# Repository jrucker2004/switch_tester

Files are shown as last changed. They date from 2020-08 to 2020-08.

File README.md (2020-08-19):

# Keyboard Switch Testing

This repository is a place to store my findings while testing switches.  The testing rig was designed and built by myself, and I plan on releasing build instructions for it once I work out all of the bugs.  

# Dislcaimers

I'm not an expert! This is just a hobby, treat it as such.

It's important to note that The data you find in this repository is for reference only.  The testing rig I'm using is calibrated using tools I have on-hand, and will very likely not create the same results as a testing rig someone else has built.  For this reason, I do not plan on releasing the raw test data.  I am making the results of my testing freely available by way of fancy looking graphs.  I'm currently using Splunk to visualize the data, but there are some downsides, like limits to how much formatting can be done to the graph, and what is displayed.  If you know of a better tool, please let me know.

# Included in this repository

You'll find the following things in this repository:

### Switch_List.csv

This is a list of the switches I have tested, or have on-hand to test.  The majority of these switches were sent to me to test by generous volunteers.  Note that some switches have been lubricated, and some have not.  Unfortunately I'm at the whim of what is sent to me, so I can only record what I've been sent to test. I would prefer to test un-lubricated switches, because method of lubrication by different users can result in different results.  If you have a switch you'd like to see tested that isn't on the list, please send me a message.

### Directories

Several directories, broken out by switch manufacturer.  In each directory, you'll find subdirectories of switch models.  In there, you'll find graphs that I've created that show the actuation force graphed against travel distance.  The vertical lines are the actuation points of the switches.  Unless otherwise noted, each switch is compressed and released 5 times.  The graphs titled "Average" are an average of all tests, showing both compression and release.  The graphs titled "Compressing" and "Releasing" show the data from all test runs.

You'll also find a directory called "Comparisons".  In this directory are graphs that compare different switches.  If there is a comparison that isn't present that you'd like to see, create an issue with the label "Comparison Request".

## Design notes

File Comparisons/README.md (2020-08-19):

### Comparisons

This directory contains visual comparisons of various switches.  To keep graphs from getting too cluttered or difficult to read, I have split them up into "Compressing" and "Releasing".

If there is a comparison you'd like to see, submit a new issue with the label "Comparison Request"

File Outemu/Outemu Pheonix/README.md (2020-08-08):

This switch ended up being very inconsistent.  I initially thought there was something wrong wtih my test rig, but the results were similar over 10 tests runs.  The way this switch implements the click function results in the place the click happens to be different depending on how the internal parts are aligned while being depressed.  The release stroke is far more consistent, however.  While investigating, if I applied pressure towards the back of the switch while depressing, the cilck happened much sooner in the stroke than if I was applying pressure towards the front of the switch.  As a result, the "Average" graph doesn't show a true representation of what this switch feels like.

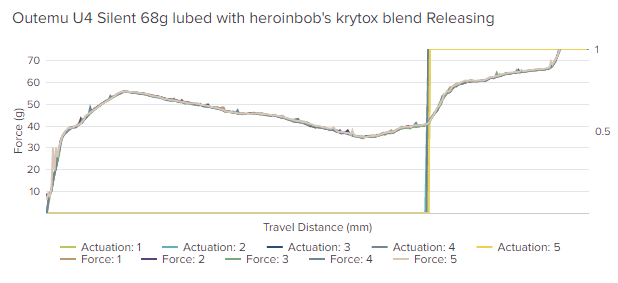
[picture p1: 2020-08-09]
Outemu/Outemu U4 Silent 68g/Outemu U4 Silent 68g Releasing.png

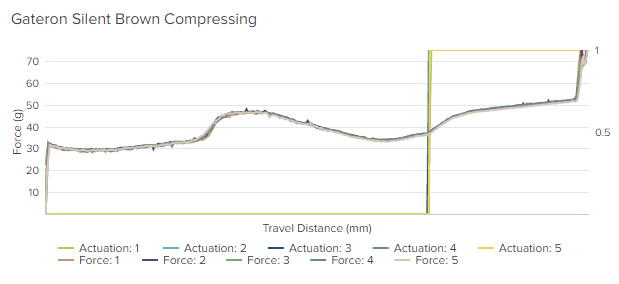
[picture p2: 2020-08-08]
Gateron/Gateron Silent Brown/Gateron Silent Brown Compressing.png

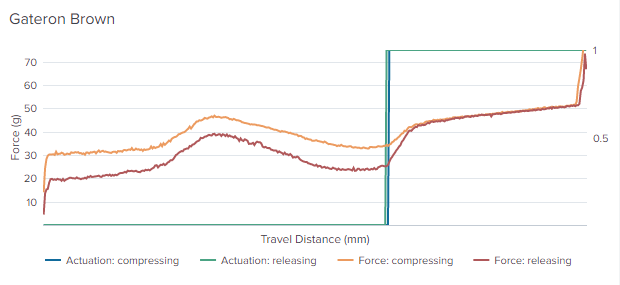
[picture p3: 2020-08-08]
Gateron/Gateron Brown/Gateron Brown Average.png

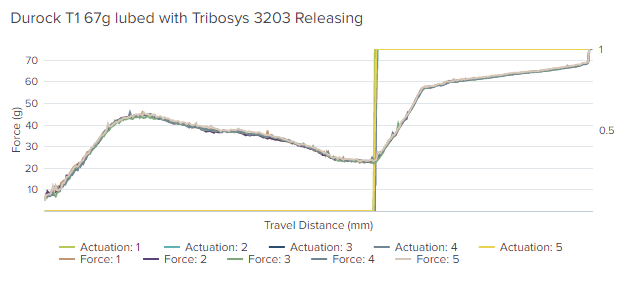
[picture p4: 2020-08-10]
Durock/Durock T1/Durock T1 67g Releasing.png

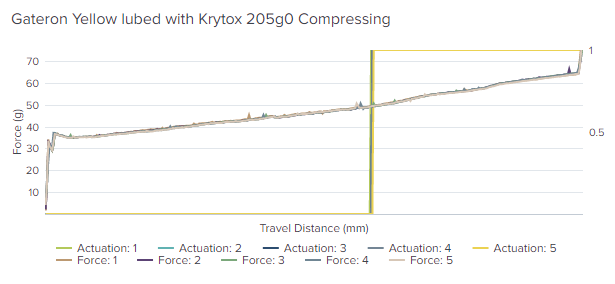
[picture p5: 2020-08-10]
Gateron/Gateron Yellow/Gateron Yellow Compressing.png

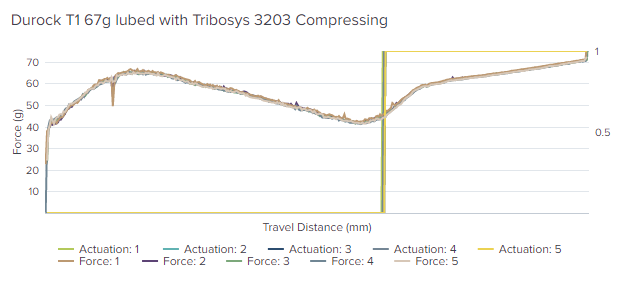
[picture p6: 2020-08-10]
Durock/Durock T1/Durock T1 67g Compressing.png

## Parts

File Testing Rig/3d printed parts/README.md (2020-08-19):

### 3D printed parts

Note:  I work in imperial (I know, I'm the worst) so these files will show up tiny when you open them in cura.  Download the barbarian plugin in Cura to fix them.

* base1
	* This file is untested.  It was modified from the version I'm currently using to try and improve how the linear rod is gripped.
* base2
	* This file is untested.  It was modified from the version I'm currently using to try and improve how the linear rod is gripped.
* coupler
	* This couples the stepper motor to the leasd screw.  The stepper motor I bought came with a coupler for a different sized lead screw, I used the set screws that came with that coupler.
* nut carrier
	* The nut for the lead screw goes into this, and is attached to the bottom of the carriage.
* nut carrier block
	* This helps hold the lead screw nut into the nut carrier.
* carriage
* fixture plate
	* I designed this to be used for more than just keyboard switches.  This fixture allows you to attach things to hold parts you want to test.
* load cell base
* pusher
* scale holder
* scale reader holder
* switch holder
	* This will hold a switch without using the fixture plate.
* switch holder 2
	* This goes with the fixture plate.

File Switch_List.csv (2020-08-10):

Switch Manufacturer | Switch Model | Tested | Lubrication
C³Equalz | Tangerine 67g | Yes | None
Durock | T1 67g | Yes | Tribosys 3203
Frankenswitch | Holy Panda | Yes | Krytox 205g0
Gateron | Brown | Yes | None
Gateron | Silent Brown | Yes | None
Gateron | Yellow | Yes | Krytox 205g0
Kailh | Box Navy | Yes | None
Novelkeys | Blueberry | Yes | heronibob’s krytox blend
Novelkeys | Cream | Yes | None
Outemu | Phoenix 68g | Yes | None
Outemu | Silent Sky 2.2 68g | Yes | Tribosys 3203
Outemu | U4 Silent 68g | Yes | heronibob’s krytox blend
Zeal | Zilent V2 65g | Yes | None

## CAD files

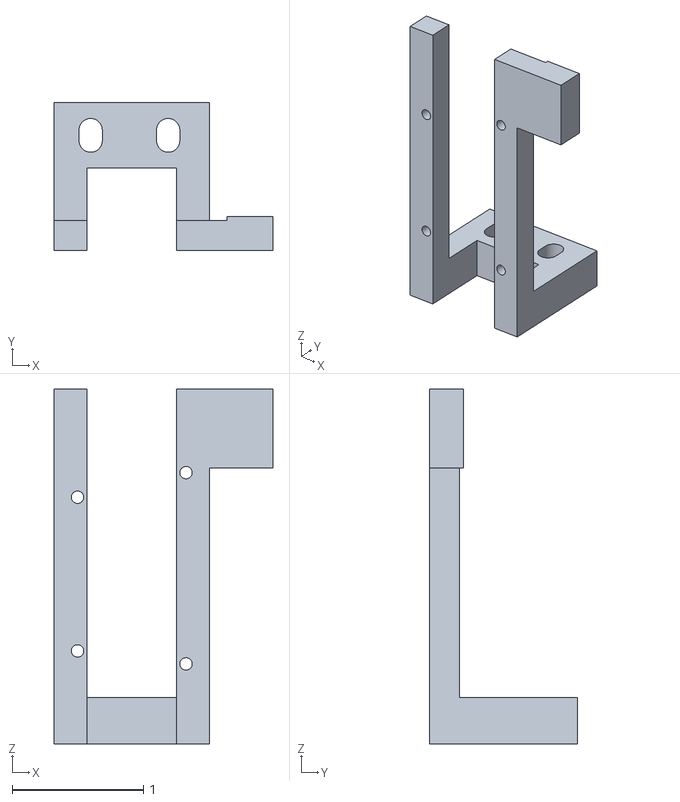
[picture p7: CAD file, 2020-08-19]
Testing Rig/3d printed parts/scale reader holder.stl
1.67 x 1.13 x 2.70

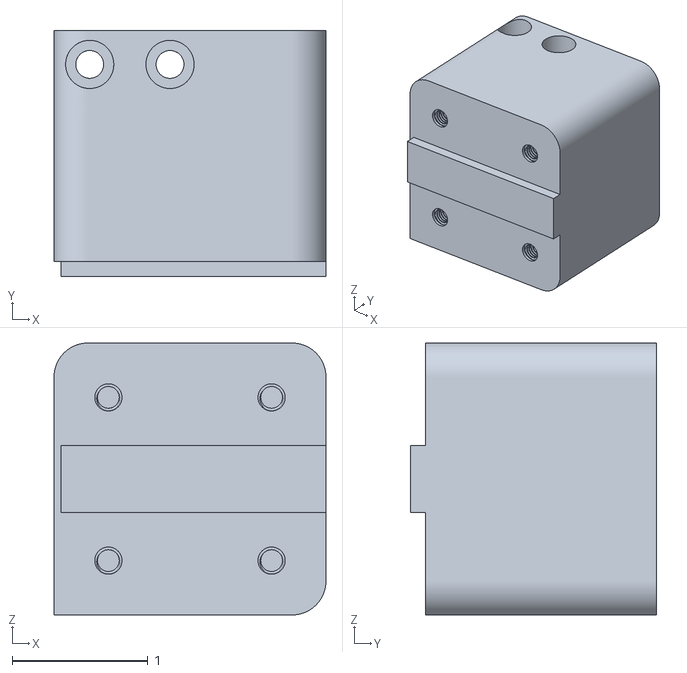
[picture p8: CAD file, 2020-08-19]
Testing Rig/3d printed parts/load cell base.stl
2.00 x 1.81 x 2.00

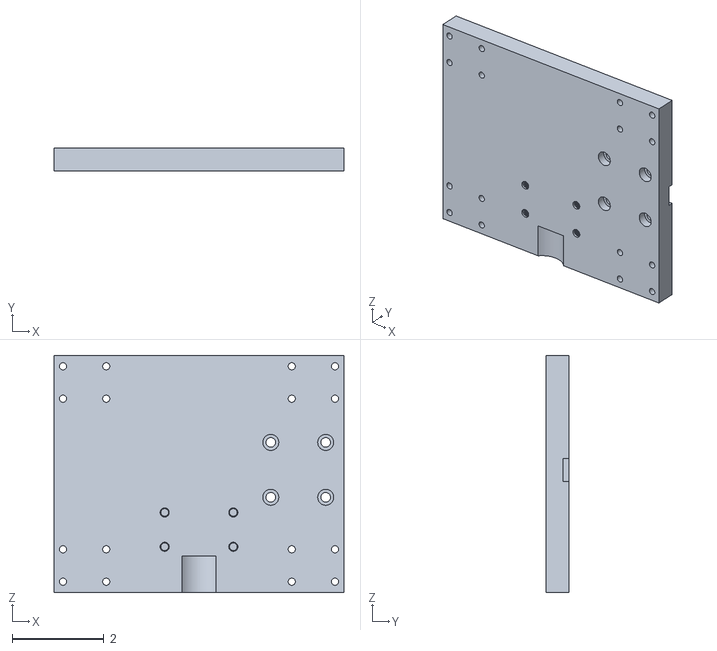
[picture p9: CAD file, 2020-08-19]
Testing Rig/3d printed parts/carriage.stl
6.34 x 0.5 x 5.18

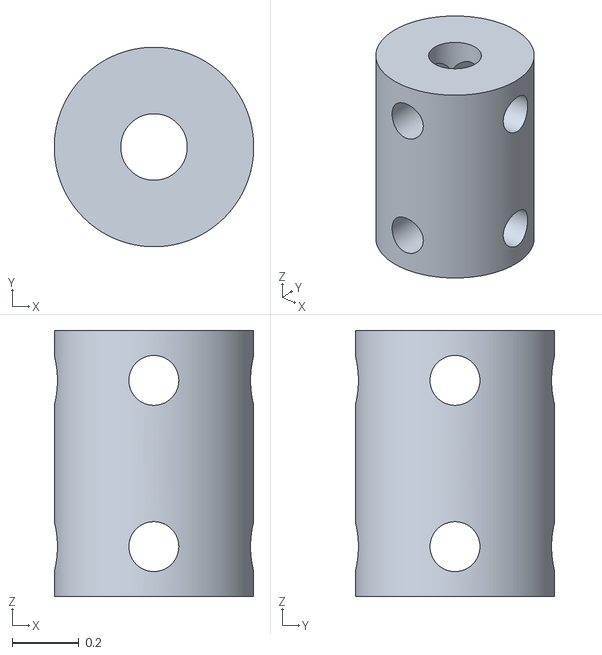
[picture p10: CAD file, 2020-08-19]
Testing Rig/3d printed parts/coupler.stl
0.6 x 0.6 x 0.8

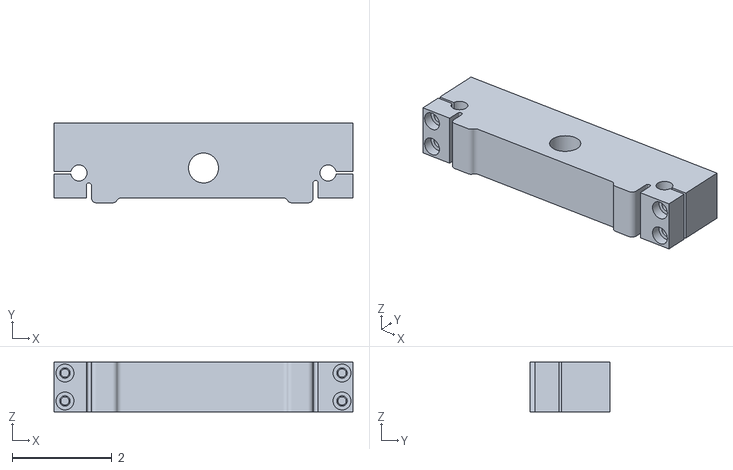
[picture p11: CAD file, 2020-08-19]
Testing Rig/3d printed parts/base2.stl
6.00 x 1.60 x 1.00

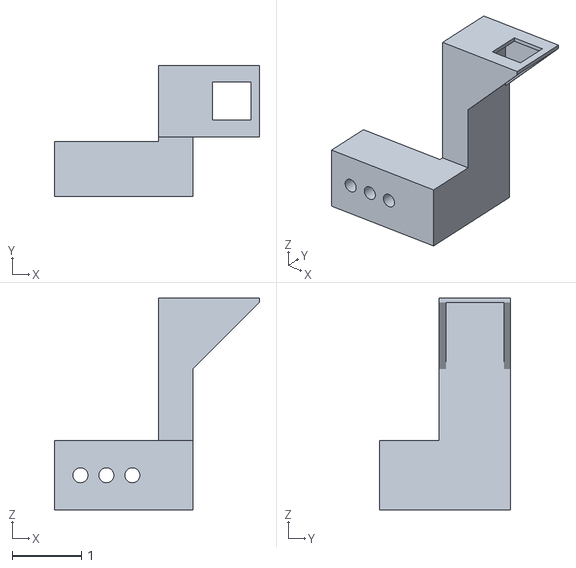
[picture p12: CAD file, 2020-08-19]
Testing Rig/3d printed parts/switch holder.stl
2.96 x 1.90 x 3.06

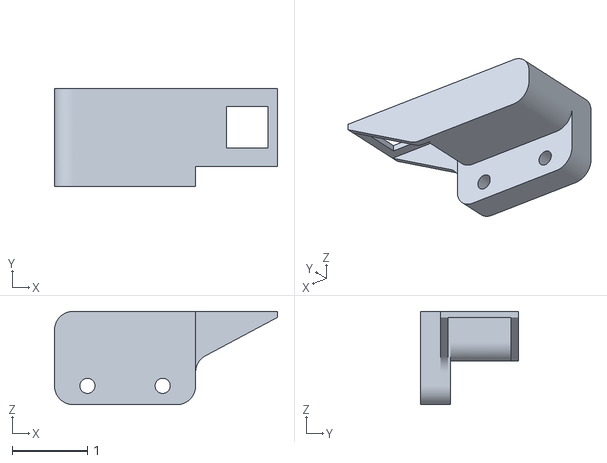
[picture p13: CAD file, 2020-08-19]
Testing Rig/3d printed parts/switch holder 2.stl
2.96 x 1.30 x 1.24

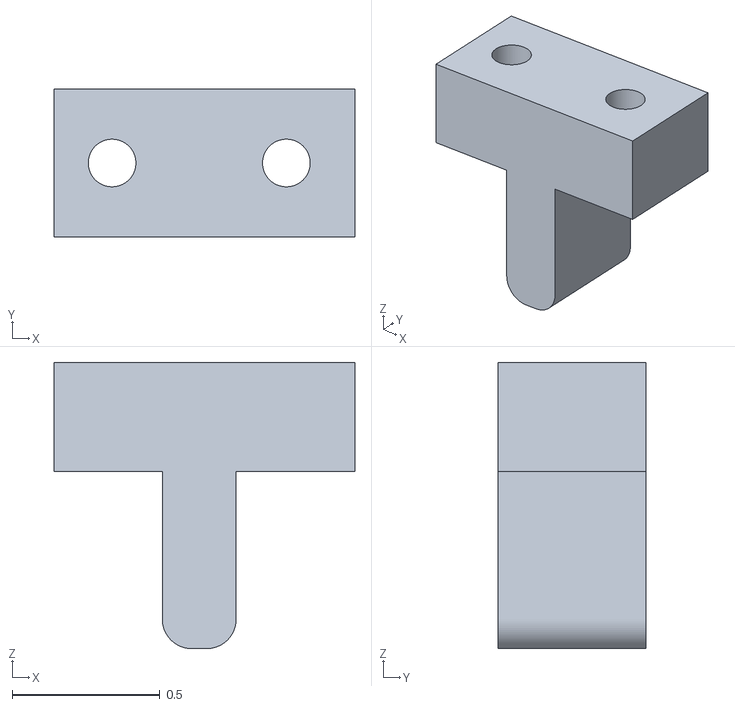
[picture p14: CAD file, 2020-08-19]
Testing Rig/3d printed parts/pusher.stl
1.02 x 0.5 x 0.97

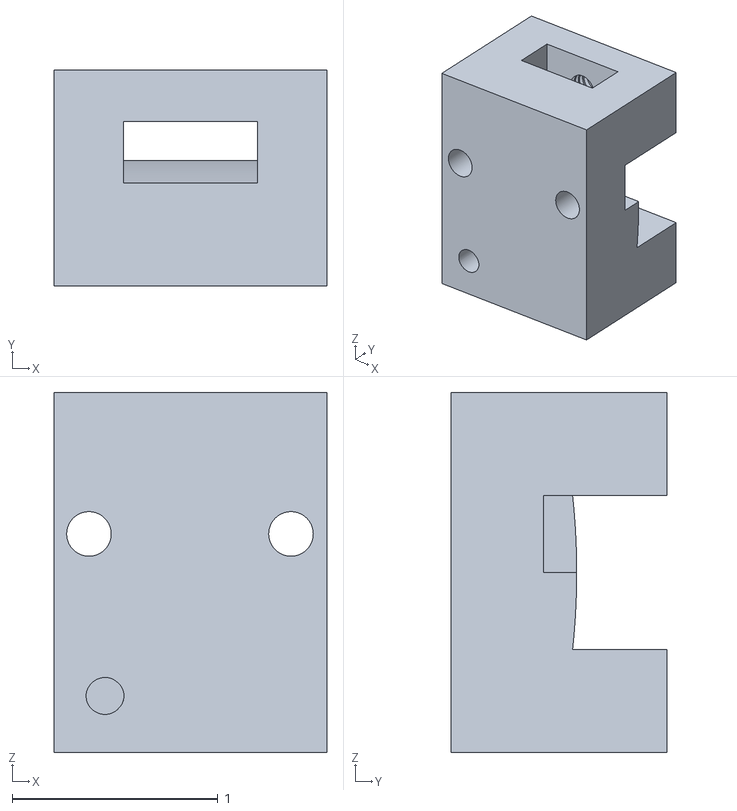
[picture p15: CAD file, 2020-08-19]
Testing Rig/3d printed parts/scale holder.stl
1.33 x 1.05 x 1.75

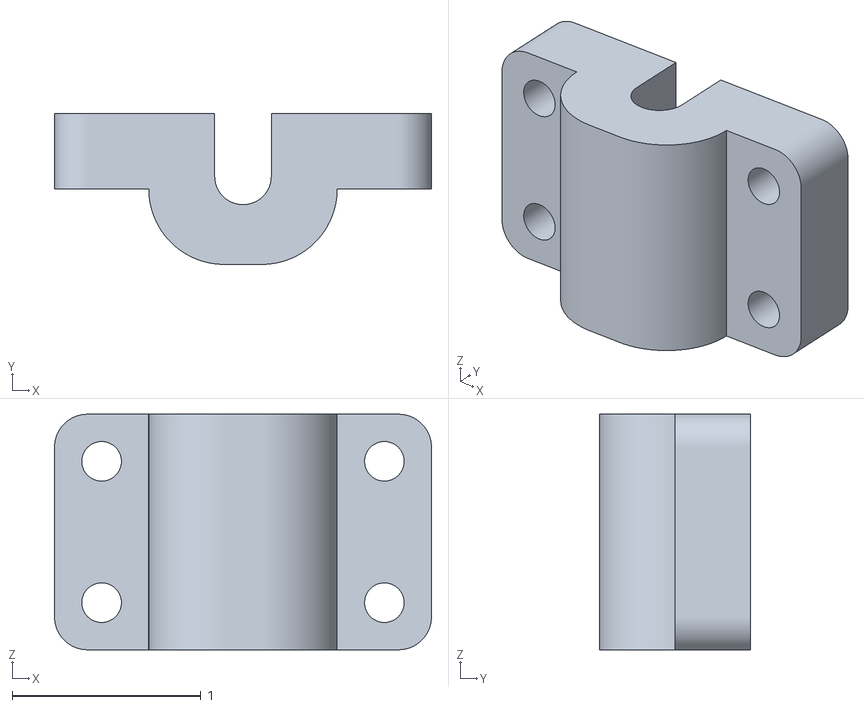
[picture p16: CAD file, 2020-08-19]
Testing Rig/3d printed parts/nut carrier.stl
2.00 x 0.8 x 1.25

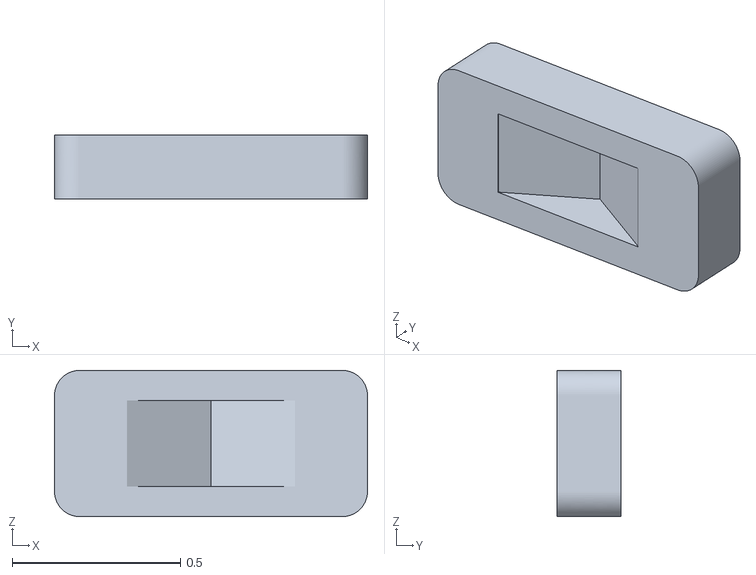
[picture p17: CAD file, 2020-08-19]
Testing Rig/3d printed parts/nut carrier block.stl
0.93 x 0.19 x 0.434

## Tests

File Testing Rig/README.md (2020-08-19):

# Testing Rig

### Overview

The purpose of this testing rig is to measure force over a distance.
Note that this was done on a budget.  All of these parts can be purchased inexpensively, but appear to be giving good results so far.  As a result of the budget, there are some limitations.  The biggest one is that the sample rate is slow enough that good force measurements cannot be taken while the stepper motor is moving.  As a result, it can take a long time to perform a test run.

### Hardware

* Load cell
	* https://www.aliexpress.com/item/32860114708.html?spm=a2g0s.9042311.0.0.5fac4c4d4d88OH
	* The load cell I used came with the load cell converter board, however I wouldn't suggest using it.
* Load Cell Converter
	* The load cell converter board is an hx711.  There are multiple versions of this board.  The one included with the load cell I purchased generations a fair amount of noise.  I've filtered out most of the noise in my code, but not all of it.  I've read that there is a version of the hx711 that uses larger capicators that remove a lot of the noise, but I haven't tested with one yet.
* Stepper motor
	* https://www.amazon.com/gp/product/B01IP7IOGQ/ref=ppx_yo_dt_b_asin_title_o06_s00?ie=UTF8&psc=1
* Linear Rails
	* https://www.aliexpress.com/item/4000215698408.html?spm=a2g0s.9042311.0.0.5fac4c4d4d88OH
	* https://www.aliexpress.com/item/4000011179319.html?spm=a2g0s.9042311.0.0.5fac4c4d4d88OH
	* The bearings I purchased were pretty gritty.  I disassembled them and cleaned them, but I would suggest spending a little more money for something better.
* Lead Screw
	* https://www.mcmaster.com/98935A703/
	* https://www.mcmaster.com/94815A007/
	* I started out with a metric lead screw, but it was way too coarse of a pitch.  I wasn't able to find a good metric leadscrew that was in my budget, so this is what I ended up using.
* Calipers
	* https://www.amazon.com/gp/product/B085PWYSPK/ref=ppx_yo_dt_b_asin_title_o01_s00?ie=UTF8&psc=1
	* You'll need some additional electronical bits to get this to work.  See the forum post below under *Resources*
	* There are lots of cheap calipers that will work, most of which have a pcb that look like they're made in the same factory.  This was the second set I purchased.  The first set was from harbor freight, and they use a different board that I wasn't able to get to work.
	* These will need to be modified to fit this project.  The fixed jaw will need to be removed, and the board will need to be removed from the sliding jaw.
* Raspberry pi
	* I used an old B+ model, just about any pi should work, as long as you have enough GPIO pins.

### Software

Full disclosure, I'm not a python expert.  Some of this code was borrowed from people smarter than me (mostly the code used to get data from the calipers.  See the forum post below for details).  The caliper code runs on python 2.7, and is not compatible with python 3.  The rest of the code runs on python 3.  If someone wants to convert the caliper code over to python 3, feel free.

### Resources

The following resources were used while building this rig:

* https://tutorials-raspberrypi.com/digital-raspberry-pi-scale-weight-sensor-hx711/
* https://www.raspberrypi.org/forums/viewtopic.php?t=120513
